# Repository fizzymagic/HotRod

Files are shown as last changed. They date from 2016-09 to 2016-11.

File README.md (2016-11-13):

# HotRod
HotRod game controller adapter to USB

## Introduction

This project allows use of a HotRod SE controller with a modern computer.  It also adds considerable 
flexibility, allowing you to remap the HotRod controls to any keys on the keyboard with *no* driver 
configuration on your PC.  Since the device emulates a USB HID keyboard, it will work with any OS that
can use the keyboard, including Windows, Mac OS, and Linux.

## Requirements

Getting the entire thing working requires:

- 32u4-based arduino clone.  I recommand the Pololu A-Star series, but it should work with any 32u4-based board.
  - The Arduino needs a Caterina (or equivalent) bootloader in it.  The Arduino Micro and the A-Star both have this as the default.
- Arduino 1.6.9 or later IDE
- A 6-pin female mini DIN connecter (aka a PS/2 keyboard connector)
- A completed circuit board with the appropriate wires from the DIN connector to the Arduino.  
  You can get a board from OSH Park
- Python 2.7.9 or later.
  - The pyserial library must be installed on the system.

## Getting Started

1. Wire the PS/2 connector to the Arduino, or populate the board.
  - The board design is in the **Hardware/** folder.
  - The board can be obtained from OSH Park [here](https://oshpark.com/shared_projects/7dNfPtaw) 
2. Copy the **HotRod/** folder into the Arduino **libraries/** folder in your Arduino user space. 
   If necessary, you may need to create the **libraries** folder.
3. Copy the **HotRodtoUSB/** folder into the Arduino user space.
4. Copy the **HotRodSetup/** folder into some other place on your computer.  It doesn't really
   matter where.
5. Compile and upload the HotRodtoUSB sketch to the Arduino.
   
## Using the HotRod-to-USB adapter

## Using SetupHotRod.py

This Python script will automatically send commands to the HotRod interface from a file.  You can
save various configurations in command files to quickly load new controller configurations.

You will need Python 2.7.9 or later, with the ```pyserial``` library installed.

### Command Line

<pre>python SetupHotRod.py [-p portname] [-s] [-d] [-r] [cmdFile] ...
         cmdFile  Name of one or more serial commands file(s).  Not required.
         -p  specify serial port, e.g. COM3 for Windows, /dev/ttyS2 for linux and Mac
             if not specified port will be autodetected
         -s  save mapping to EEPROM after processing file
         -d  dump current mapping after processing file
         -r  reset mapping to default before processing file
         -l  reinitialize mapping from EEPROM before processing file</pre>

### Serial Command Set

The following commands are available to be sent to the HotRod interface from SetupHotRod.py; the input file
should consist of one command per line.

- **M sc kb**: Map scan code *sc* to  keyboard key *kb*
  - The scan code and keyboard key can be specified in ways:
    1. As a macro (all macros are defined in HotRod.py)
    2. As a 2-digit hexadecimal number
  - Additionally, the keyboard key can be specified:
    3. As an ASCII character
- **S**: Save the current key mapping to EEPROM
- **R**: Reset the key mapping to the original (in PROGMEM)
- **L**: Load a key mapping from EEPROM
- **D**: Dump the current key mapping
- **?**: Echo "HotRod" to serial port

### Examples:

```M HR_LEFT_JOYSTICK_UP KB_UP_ARROW```  
Maps the left joystick up to the keyboard up arrow.

```M 75 DA```  
Also maps the left joystick up to the keyboard up arrow.

```M HR_LEFT_JOYSTICK_UP i```  
Maps the left joystick up to ASCII 'i'

### Included command files

- SE_MAME_default.hrm
  - Default MAME configuration for 2 players.
- SE_MAME_2joy.hrm
  - Default MAME configuration for 2-joystick games.

## Additional Information

### Pin setup:

```
DIN-6 Pin    Arduino Pin
   1             D2
   3             GND
   4             +5V
   5             D3
```

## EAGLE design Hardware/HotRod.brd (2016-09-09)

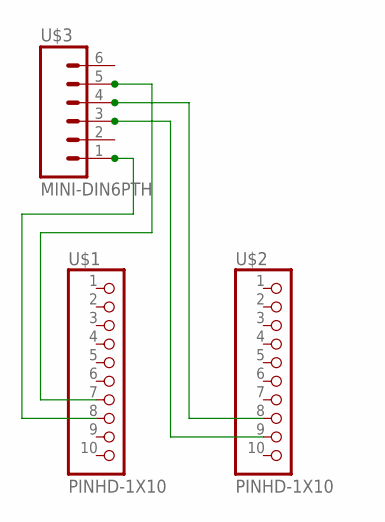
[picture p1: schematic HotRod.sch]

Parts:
U$1, U$2: PINHD-1X10; 1X10-BIG
U$3: MINI-DIN6PTH; MINI-DIN6

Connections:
unnamed: U$1.8, U$3.1
unnamed: U$1.7, U$3.5
unnamed: U$2.8, U$3.4
unnamed: U$2.9, U$3.3

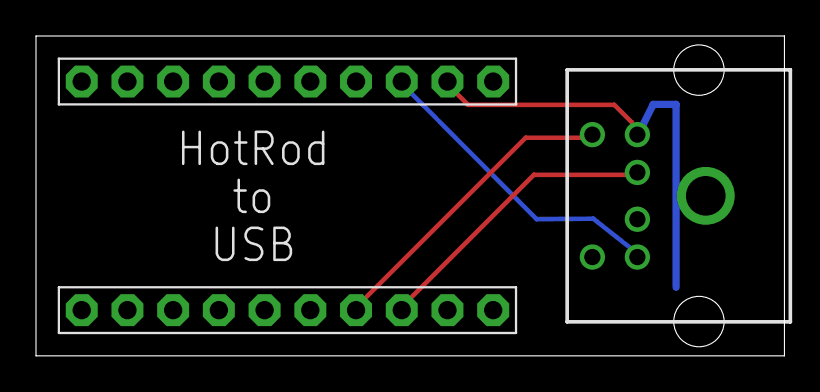
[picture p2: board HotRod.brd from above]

Board: 2 copper layers, 41.6 x 17.8 mm, 3 parts (0 on the bottom side), 4 nets.

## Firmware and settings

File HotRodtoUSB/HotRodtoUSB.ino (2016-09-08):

#include <Keyboard.h>
#include <stdlib.h>
#include <Arduino.h>
#include <HotRod.h>

#define DATA_PIN     2
#define CLOCK_PIN    3
#define EEPromKeys   0
#define EEPromMagic  CODESIZE
#define MAGIC        0xAA
#define BUFFERSIZE   64
#define END_COMMAND  '\n'

HotRod HR;
uint8_t scanCodes[CODESIZE];
uint8_t outputKeys[CODESIZE];
bool breakMode = false;

// Initial setup function
void setup() {
  Serial.begin(9600);
  // Load the scan codes from PROGMEM into RAM
  loadScanCodes();
  // Load the current key mapping from EEPROM or PROGMEM
  loadOutputKeys();
  // Start receiving data from the HotRod
  HR.begin(DATA_PIN, CLOCK_PIN);
  pinMode(9, OUTPUT);
  digitalWrite(9, HIGH);
}

// The main loop that is always running
void loop() {
  int i;
  uint8_t ch, k;
  
  // Wait for a scan code from the HotRod
  while (!HR.available()) {
    // Check to see if anything on serial port
    if (Serial.available() > 0) {
      getComms();
    }
  }
  // F0 indicates that it will be a key release
  ch = HR.read();
  if (ch == 0xF0) {
    breakMode = true;
    return;
  }
  // Find the scan code in the table
  i = findScanCode(ch);
  if (i >= 0) {
    // Output the corresponding key to the USB
    k = outputKeys[i];
    if (k != 0) {
      digitalWrite(9, LOW);
      
      if (breakMode) {
        Keyboard.release(k);
        breakMode = false;
      }
      else {
        Keyboard.press(k);
      }
      digitalWrite(9, HIGH);
    }
  }
}

// This function reads the input from the serial port.
// Bytes are stored in a buffer (circular) longer than the longest command.
// No command processing is done until it sees a \n character.
void getComms(void) {
  static int offset = 0;
  static uint8_t buffer[BUFFERSIZE];
  while (Serial.available() > 0) {
    uint8_t ch = Serial.read();
    if (ch == END_COMMAND || ch == 0) {
      buffer[offset] = 0;
      offset = 0;
      processCommand(buffer);
    }
    else {
      buffer[offset++] = ch;
      if (offset >= BUFFERSIZE) {
        offset = 0;
      }
    }
  }
}

// Process the command string
void processCommand(const uint8_t *buffer) {
  uint8_t cmd = toupper(*buffer);
  uint8_t from, to;
  int key;
  switch(cmd) {
    case 'M':
      Serial.print("Map ");
      if (parseMapCommand(buffer, &from, &to)) {
        if ((key = findScanCode(from)) >= 0) {
          outputKeys[key] = to;
          Serial.print(from, HEX);
          Serial.print(" to ");
          Serial.print(to, HEX);
          Serial.print(" ");
        }
        else {
          Serial.print("unknown scan code$");
          return;
        }
      }
      else {
        Serial.print("parse error$");
        return;
      }
      break;
    case 'S':
      saveOutputKeys();
      Serial.print("Save ");
      break;
    case 'R':
      resetOutputKeys();
      Serial.print("Reset ");
      break;
    case 'L':
      loadOutputKeys();
      Serial.print("Reload ");
      break;
    case '?':
      Serial.print("HotRod$");
      return;
    case 'D':
      for (int i = 0; i < CODESIZE; i++) {
        Serial.print(i);
        Serial.print(": ");
        Serial.print(scanCodes[i], HEX);
        Serial.print(" => ");
        Serial.println(outputKeys[i], HEX);
      }
      break;
    default:
      Serial.print("Unknown command$");
      return;
  }
  Serial.print("OK$");
}

// Binary search of key codes. 
// If the result of the search is not a key code in the set, returns -1
int findScanCode(uint8_t target) {
  int iMin = 0, iMax = CODESIZE - 1, iMiddle;
  int ctr = 0;
  uint8_t c;
  while (iMin <= iMax) {
    iMiddle = (iMax + iMin) / 2;
    c = scanCodes[iMiddle];
    if (c > target) {
      iMax = iMiddle - 1;
    } else if (c < target) {
      iMin = iMiddle + 1;
    } else if (c == target) {
      iMin = iMiddle;
      break;
    }
    else if (++ctr > 6) {
      return -1;
    }
  }
  if (scanCodes[iMin] == target) {
    return iMin;
  }
  else {
    return -1;
  }
}

// Copy scan codes from PROGMEM into RAM
void loadScanCodes(void) {
  memcpy_P(scanCodes, HotRodCodes, CODESIZE);
}

// Copy output key mapping from EEPROM or PROGMEM into RAM
void loadOutputKeys(void) {
  if (eeprom_read_byte((const uint8_t *) EEPromMagic) == MAGIC) {
    eeprom_read_block(outputKeys, (const uint8_t *) EEPromKeys, CODESIZE);
  }
  else {
    memcpy_P(outputKeys, DefaultKeys, CODESIZE);
  }
}

// Reset key mappings from PROGMEM
void resetOutputKeys(void) {
  memcpy_P(outputKeys, DefaultKeys, CODESIZE);
}

// Save current key mapping to EEPROM
void saveOutputKeys(void) {
  eeprom_update_block(outputKeys, (uint8_t *) EEPromKeys, CODESIZE);
  eeprom_update_byte((uint8_t *) EEPromMagic, MAGIC);
}

// Parsing for the map command, which is the most complex.
bool parseMapCommand(const uint8_t *buffer, uint8_t *from, uint8_t *to) {
  int bufLength = strlen((char *) buffer);
  int i = 0, j = 0;
  uint8_t tmp[16], ch;
  while (buffer[i] != ' ' && i < bufLength) i++;
  while (buffer[i] == ' ' && i < bufLength) i++;
  while ((ch = buffer[i]) != ' ' && j < 16 && i < bufLength) {
    i++;
    if (ch == 0 || i >= bufLength) return false;
    else {
      tmp[j++] = ch;
    }
  }
  if (j != 2) {
    return false;
  }
  tmp[j] = 0;
  *from = strtoul((const char *) tmp, NULL, 16);
  j = 0;
  while (buffer[i] == ' ' && i < bufLength) i++;
  while ((ch = buffer[i]) != 0 && j < 16 && i < bufLength) {
    i++;
    tmp[j++] = ch;
    if (ch == 0 || i >= bufLength) break;
  }
  if (j != 2) {
    return false;
  }
  tmp[j] = 0;
  *to = strtoul((const char *) tmp, NULL, 16);
  return true;
}

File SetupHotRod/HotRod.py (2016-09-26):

import serial, sys, os, glob, threading

HRCodes = {
    'HR_ONE_PLAYER'          :0x16,
    'HR_TWO_PLAYER'          :0x1E,
    'HR_LEFT_JOYSTICK_UP'    :0x75,
    'HR_LEFT_JOYSTICK_DOWN'  :0x72,
    'HR_LEFT_JOYSTICK_RIGHT' :0x74,
    'HR_LEFT_JOYSTICK_LEFT'  :0x6B,
    'HR_LEFT_BUTTON_SIDE'    :0x26,
    'HR_LEFT_BUTTON_1'       :0x14,
    'HR_LEFT_BUTTON_2'       :0x11,
    'HR_LEFT_BUTTON_3'       :0x29,
    'HR_LEFT_BUTTON_4'       :0x12,
    'HR_LEFT_BUTTON_5'       :0x1A,
    'HR_LEFT_BUTTON_6'       :0x22,
    'HR_LEFT_BUTTON_7'       :0x21,
    'HR_RIGHT_JOYSTICK_UP'   :0x2D,
    'HR_RIGHT_JOYSTICK_DOWN' :0x2B,
    'HR_RIGHT_JOYSTICK_RIGHT':0x34,
    'HR_RIGHT_JOYSTICK_LEFT' :0x23,
    'HR_RIGHT_BUTTON_SIDE'   :0x25,
    'HR_RIGHT_BUTTON_1'      :0x1C,
    'HR_RIGHT_BUTTON_2'      :0x1B,
    'HR_RIGHT_BUTTON_3'      :0x15,
    'HR_RIGHT_BUTTON_4'      :0x1D,
    'HR_RIGHT_BUTTON_5'      :0x24,
    'HR_RIGHT_BUTTON_6'      :0x54,
    'HR_RIGHT_BUTTON_7'      :0x5B,
}

KBKeys ={
    'KEY_SPACEBAR'        :0x20,
    'KEY_LEFT_CTRL'       :0x80,
    'KEY_LEFT_SHIFT'      :0x81,
    'KEY_LEFT_ALT'        :0x82,
    'KEY_LEFT_GUI'        :0x83,
    'KEY_RIGHT_CTRL'      :0x84,
    'KEY_RIGHT_SHIFT'     :0x85,
    'KEY_RIGHT_ALT'       :0x86,
    'KEY_RIGHT_GUI'       :0x87,
    'KEY_UP_ARROW'        :0xDA,
    'KEY_DOWN_ARROW'      :0xD9,
    'KEY_LEFT_ARROW'      :0xD8,
    'KEY_RIGHT_ARROW'     :0xD7,
    'KEY_BACKSPACE'       :0xB2,
    'KEY_TAB'             :0xB3,
    'KEY_ENTER'           :0xB0,
    'KEY_RETURN'          :0xB0,
    'KEY_ESC'             :0xB1,
    'KEY_INSERT'          :0xD1,
    'KEY_DELETE'          :0xD4,
    'KEY_PAGE_UP'         :0xD3,
    'KEY_PAGE_DOWN'       :0xD6,
    'KEY_HOME'            :0xD2,
    'KEY_END'             :0xD5,
    'KEY_CAPSLOCK'        :0xC1,
    'KEY_CAPS_LOCK'       :0xC1,
    'KEY_F1'              :0xC2,
    'KEY_F2'              :0xC3,
    'KEY_F3'              :0xC4,
    'KEY_F4'              :0xC5,
    'KEY_F5'              :0xC6,
    'KEY_F6'              :0xC7,
    'KEY_F7'              :0xC8,
    'KEY_F8'              :0xC9,
    'KEY_F9'              :0xCA,
    'KEY_F10'             :0xCB,
    'KEY_F11'             :0xCC,
    'KEY_F12'             :0xCD,
    'KEY_KEYPAD_NUMLOCK'  :0xDB,
    'KEY_KEYPAD_SLASH'    :0xDC,
    'KEY_KEYPAD_STAR'     :0xDD,
    'KEY_KEYPAD_MINUS'    :0xDE,
    'KEY_KEYPAD_PLUS'     :0xDF,
    'KEY_KEYPAD_ENTER'    :0xE0,
    'KEY_KEYPAD_1'        :0xE1,
    'KEY_KEYPAD_2'        :0xE2,
    'KEY_KEYPAD_3'        :0xE3,
    'KEY_KEYPAD_4'        :0xE4,
    'KEY_KEYPAD_5'        :0xE5,
    'KEY_KEYPAD_6'        :0xE6,
    'KEY_KEYPAD_7'        :0xE7,
    'KEY_KEYPAD_8'        :0xE8,
    'KEY_KEYPAD_9'        :0xE9,
    'KEY_KEYPAD_0'        :0xEA,
    'KEY_KEYPAD_POINT'    :0xEB,
}

def getSerialPorts():
    """ Lists serial port names

        :raises EnvironmentError:
            On unsupported or unknown platforms
        :returns:
            A list of the serial ports available on the system
    """
    if sys.platform.startswith('win'):
        ports = ['COM%s' % (i + 1) for i in range(256)]
    elif sys.platform.startswith('linux') or sys.platform.startswith('cygwin'):
        # this excludes your current terminal "/dev/tty"
        ports = glob.glob('/dev/tty[A-Za-z]*')
    elif sys.platform.startswith('darwin'):
        ports = glob.glob('/dev/tty.*')
    else:
        raise EnvironmentError('Unsupported platform')

    result = []
    for port in ports:
        try:
            s = serial.Serial(port)
            s.close()
            result.append(port)
        except (OSError, serial.SerialException):
            pass
    return result
    
def getResponse(serialPort, endChar, maxChars = 32):
    ctr = 0
    response = ''
    try:
        c = serialPort.read(1)
        while c != endChar and c != 0 and ctr < maxChars:
            ctr += 1
            response += c
            # print "c = %02X" % (int(c))
            c = serialPort.read()
    except:
        pass
    return response
    
def checkPort(port, i, results):
    HRPort = ''
    response = ''
    try:
        sp = serial.Serial(port = port, baudrate = 9600, bytesize = serial.EIGHTBITS, parity= serial.PARITY_NONE, stopbits = serial.STOPBITS_ONE, timeout = 0.2, write_timeout = 1)
        if (sp.write('?\n') == 2):
            response = getResponse(sp, '$')
    except:
        pass
    if response.strip() == 'HotRod':
        results[i] = port
    sp.close()
    return
    
def findHotRod():
    ports = getSerialPorts()
    results = ['' for p in ports]
    threads = []
    for i, port in enumerate(ports):
        t = threading.Thread(name="port%d" % i, target=checkPort, args = (port,i,results,))
        t.setDaemon(True)
        threads.append(t)
        t.start()
        
    finished = False        
    while not finished:
        for t in threads:
            if not t.isAlive():
                finished = True
                break
    result =  [r for r in results if len(r) > 1]
    if len(result) > 0:
        return result[0]
    else:
        return None
                    
    
    
                
    
        
    
        
        

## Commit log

2016-09-04 Threads for port detection working. Python to send keymap working.
2016-09-07 Added new map files; cleaned up Arduino project to work with newest IDE.
2016-09-09 Added Hardware folder
    [HotRod.brd, HotRod.sch]
2018-02-19 Fixed a couple of unknown bugs
    [SetupHotRod.py]

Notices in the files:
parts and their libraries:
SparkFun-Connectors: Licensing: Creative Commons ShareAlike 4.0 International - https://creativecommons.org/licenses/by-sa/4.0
